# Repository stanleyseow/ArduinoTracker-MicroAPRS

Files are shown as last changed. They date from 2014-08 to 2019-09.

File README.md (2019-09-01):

Arduino APRS SVTrackR
=====================

 - Written by Stanley Seow ( 9W2SVT / N5SVT )
 - e-mail : stanleyseow@gmail.com
 
 *** Pls refer to the top of the source code for version history and updated instructions.

 This sketch configure the MicroAPRS (the modem) for the proper callsign and ssid and read/write data coming in from the MicroAPRS (another Arduino/atmega328P with bootloader) via Serial port

 Library needed :-
 
 * AltSoftSerial ( https://www.pjrc.com/teensy/td_libs_AltSoftSerial.html )
 * tinyGPS++ ( http://arduiniana.org/libraries/tinygpsplus/ )
 * SSD1306 OLED Text only ( https://github.com/stanleyseow/ArduinoTracker-MicroAPRS/tree/master/libraries/SSD1306_text )
 * MicroAPRS libs 
 
 Instructions :-
 
 Download the MicroAPRS compiled Modem.hex from https://github.com/markqvist/MicroAPRS/
 
 As this hex is not compiled from the Arduino IDE, you need to manually upload this hex to the Arduino with a bootloader using avrdude or Xloader.
 
Xloader to load this hex image to the Arduino / Mini Pro :-
 
    1. Download the Xloader : http://russemotto.com/xloader/
    2. Copy modem.hex into Xloader folder
    3. Select the modem hex file 
    4. Select UNO for UNO or Duemilanove/328 for Mini Pro
    5. Select the COM port and press Upload

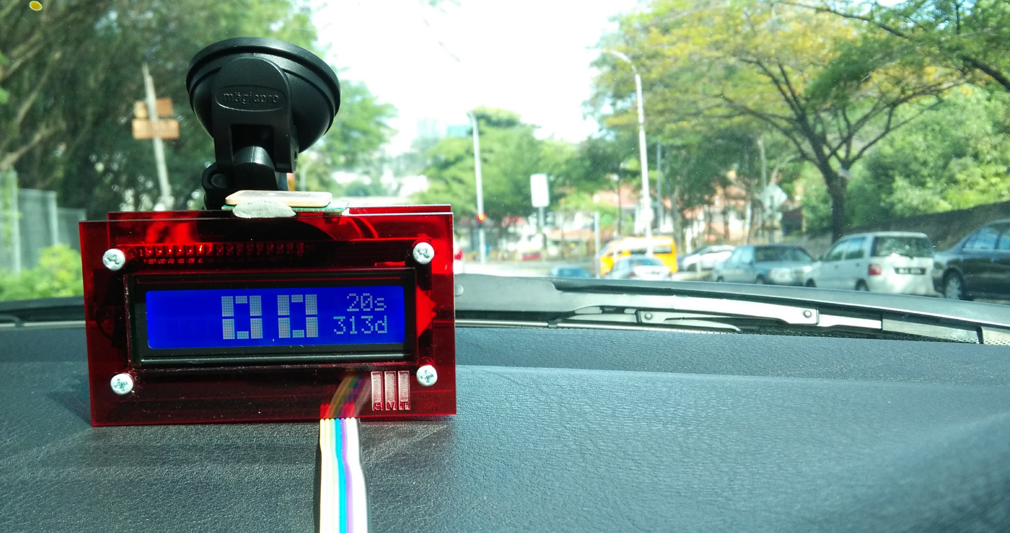
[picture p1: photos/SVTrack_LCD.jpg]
SVTrack LCD
 

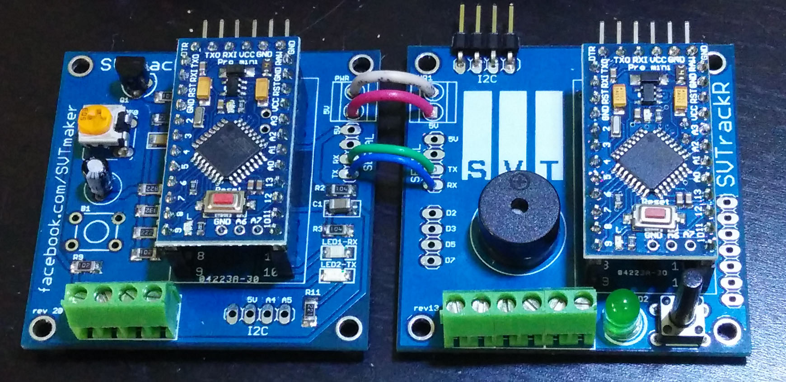
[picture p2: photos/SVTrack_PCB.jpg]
SVTrack PCB
    
    
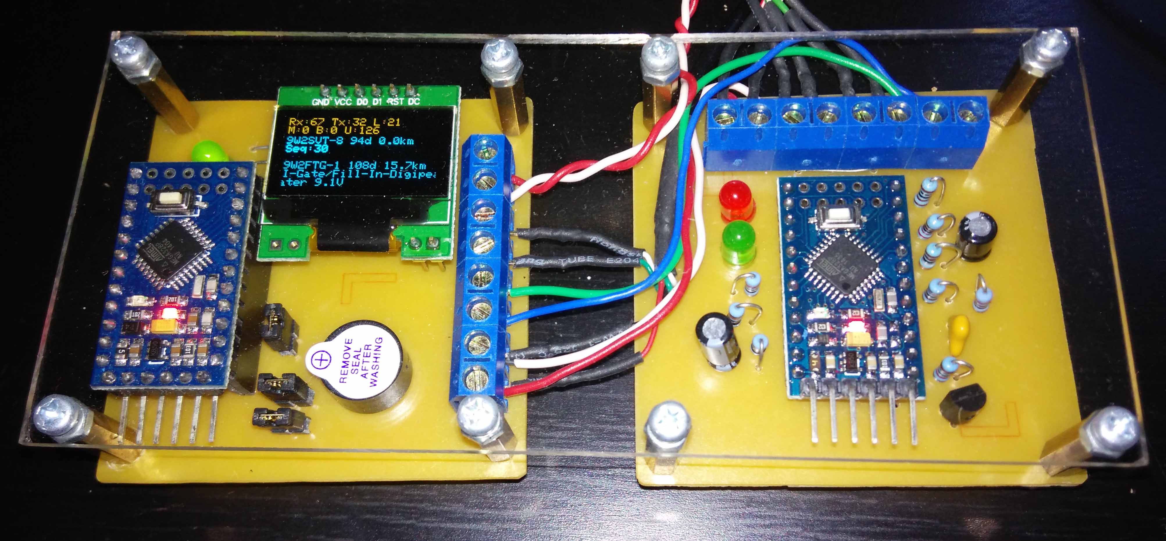
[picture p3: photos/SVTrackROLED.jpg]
SVTrackR with OLED


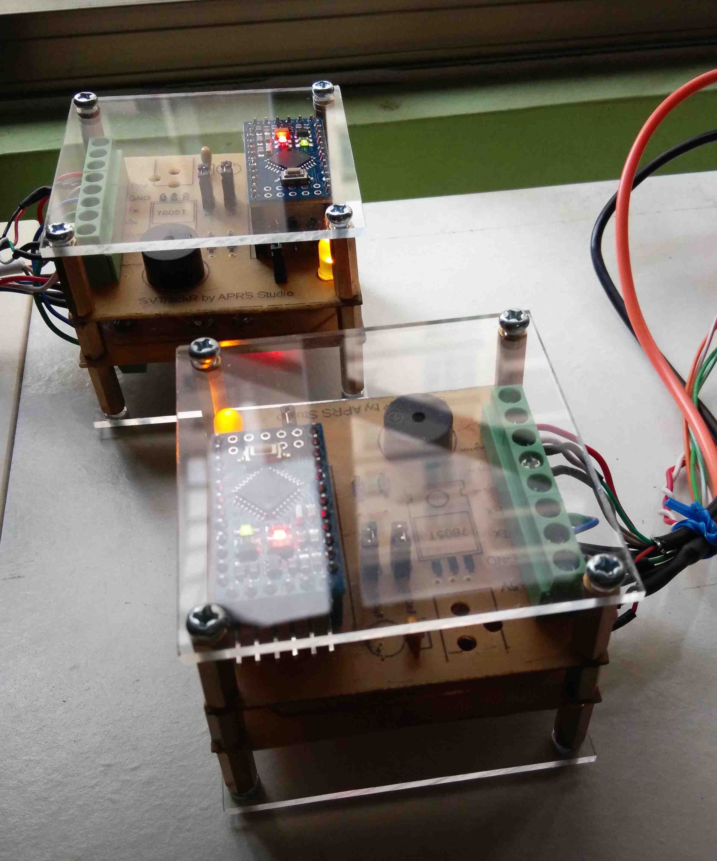
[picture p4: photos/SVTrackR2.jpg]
SVTrackR


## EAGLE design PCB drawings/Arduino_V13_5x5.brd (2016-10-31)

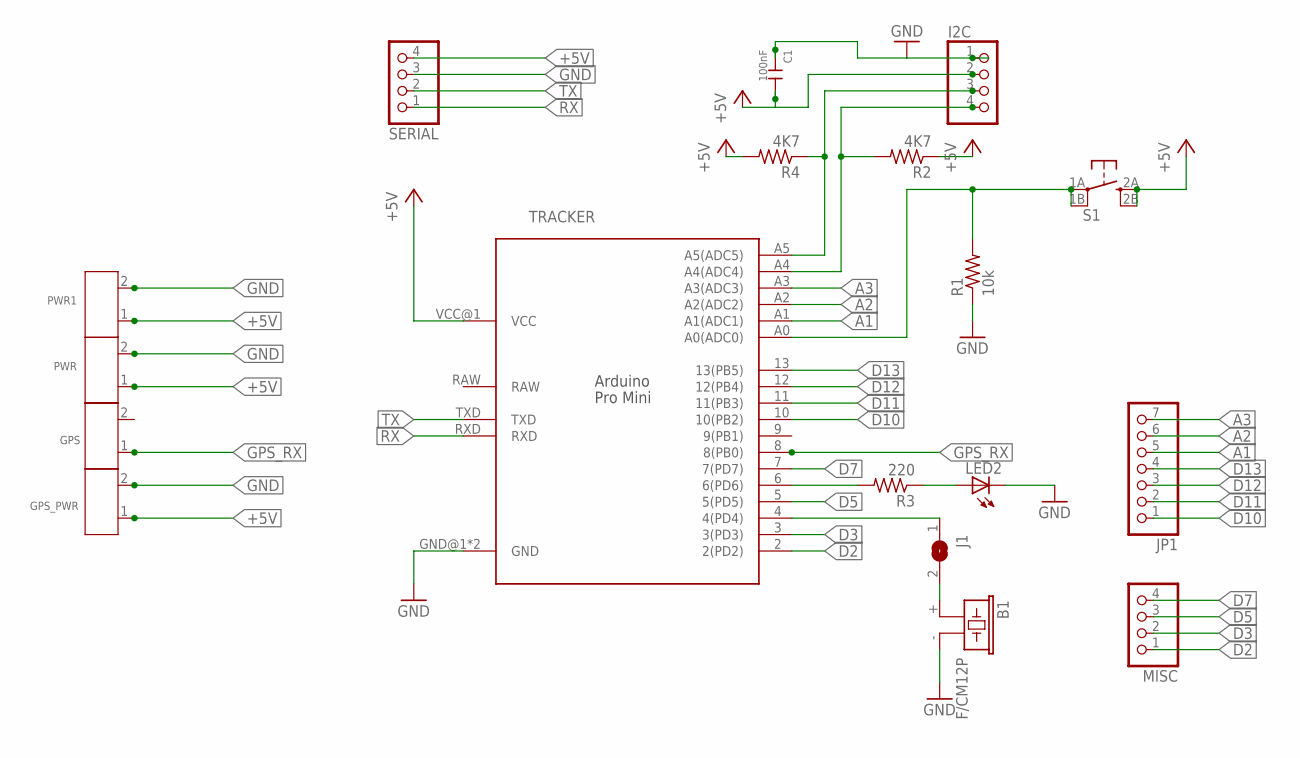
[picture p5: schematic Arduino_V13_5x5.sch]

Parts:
B1: F/CM12P
C1: 100nF; C1206
GPS: SCREW-TERMINAL-GREEN(2P-3.5); H2-3.5-7.0X7.0MM
GPS_PWR: SCREW-TERMINAL-GREEN(2P-3.5); H2-3.5-7.0X7.0MM
I2C: PINHD-1X4; 1X04
J1: SJ
JP1: PINHD-1X7; 1X07
LED2: LED5MM
MISC: PINHD-1X4; 1X04
PWR, PWR1: SCREW-TERMINAL-GREEN(2P-3.5); H2-3.5-7.0X7.0MM
R1: 10k; M1206
R2, R4: 4K7; M1206
R3: 220; M1206
S1: TACTILETACT-6X6-PTH; TACTILE-PTH
SERIAL: PINHD-1X4; 1X04
TRACKER: PRO-MINI

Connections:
+5V: C1.2, GPS_PWR.1, I2C.2, PWR.1, PWR1.1, R2.1, R4.2, S1.2A, S1.2B, SERIAL.4, TRACKER.VCC@1 (VCC)
A1: JP1.5, TRACKER.A1 (A1(ADC1))
A2: JP1.6, TRACKER.A2 (A2(ADC2))
A3: JP1.7, TRACKER.A3 (A3(ADC3))
A4: I2C.4, R2.2, TRACKER.A4 (A4(ADC4))
BUTTON: R1.2, S1.1A, S1.1B, TRACKER.A0 (A0(ADC0))
BUZZER: J1.1, TRACKER.4 (4(PD4))
D2: MISC.1, TRACKER.2 (2(PD2))
D3: MISC.2, TRACKER.3 (3(PD3))
D5: MISC.3, TRACKER.5 (5(PD5))
D7: MISC.4, TRACKER.7 (7(PD7))
D10: JP1.1, TRACKER.10 (10(PB2))
D11: JP1.2, TRACKER.11 (11(PB3))
D12: JP1.3, TRACKER.12 (12(PB4))
D13: JP1.4, TRACKER.13 (13(PB5))
GND: B1.- (2), C1.1, GPS_PWR.2, I2C.1, LED2.K (C), PWR.2, PWR1.2, R1.1, SERIAL.3, TRACKER.GND@1 (GND), TRACKER.GND@2 (GND)
GPS_RX: GPS.1, TRACKER.8 (8(PB0))
unnamed: I2C.3, R4.1, TRACKER.A5 (A5(ADC5))
unnamed: LED2.A, R3.1
unnamed: R3.2, TRACKER.6 (6(PD6))
unnamed: B1.+ (1), J1.2
RX: SERIAL.1, TRACKER.RXD
TX: SERIAL.2, TRACKER.TXD

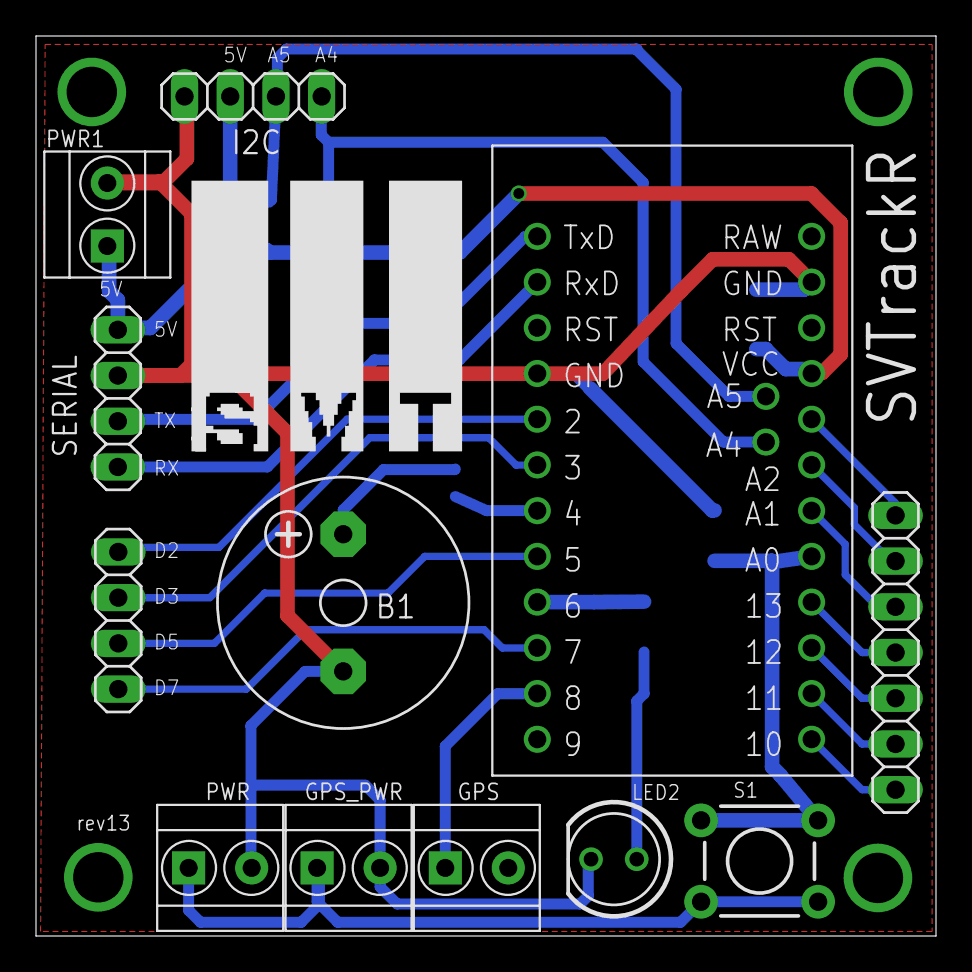
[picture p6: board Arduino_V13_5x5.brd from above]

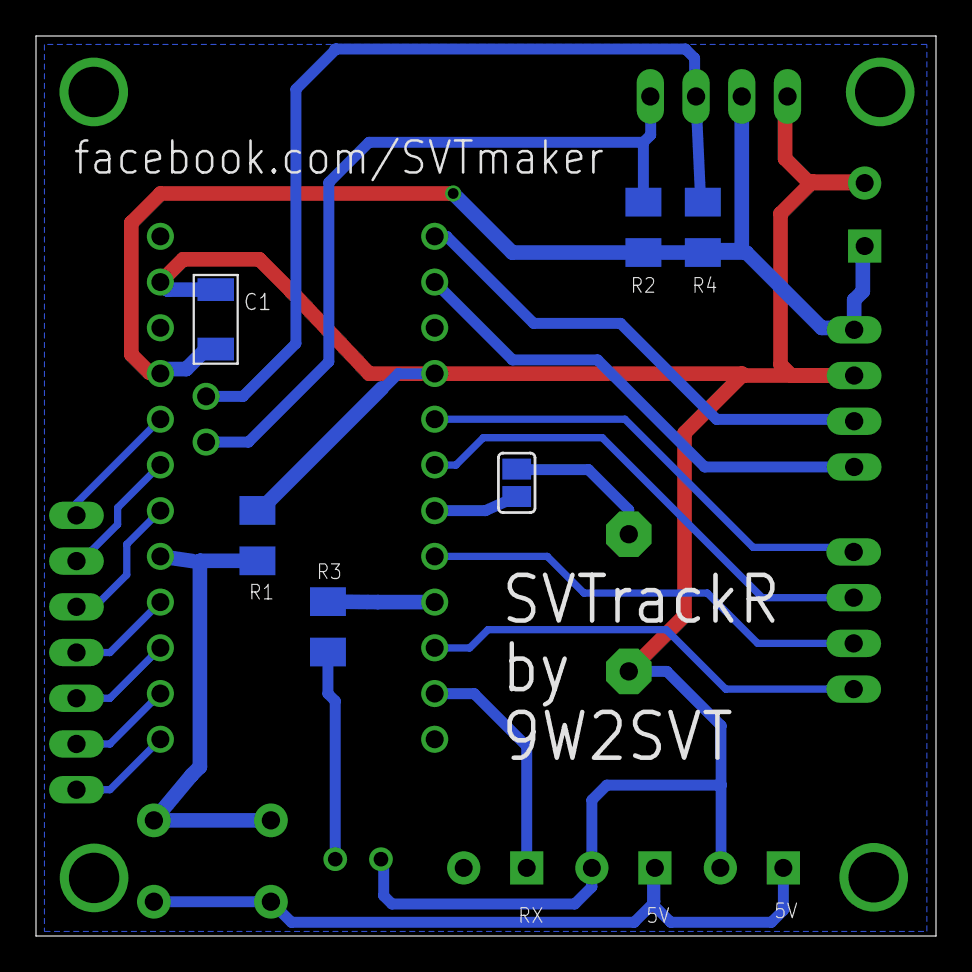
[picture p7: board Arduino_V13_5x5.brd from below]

Board: 2 copper layers, 50.0 x 50.0 mm, 18 parts (6 on the bottom side), 23 nets.

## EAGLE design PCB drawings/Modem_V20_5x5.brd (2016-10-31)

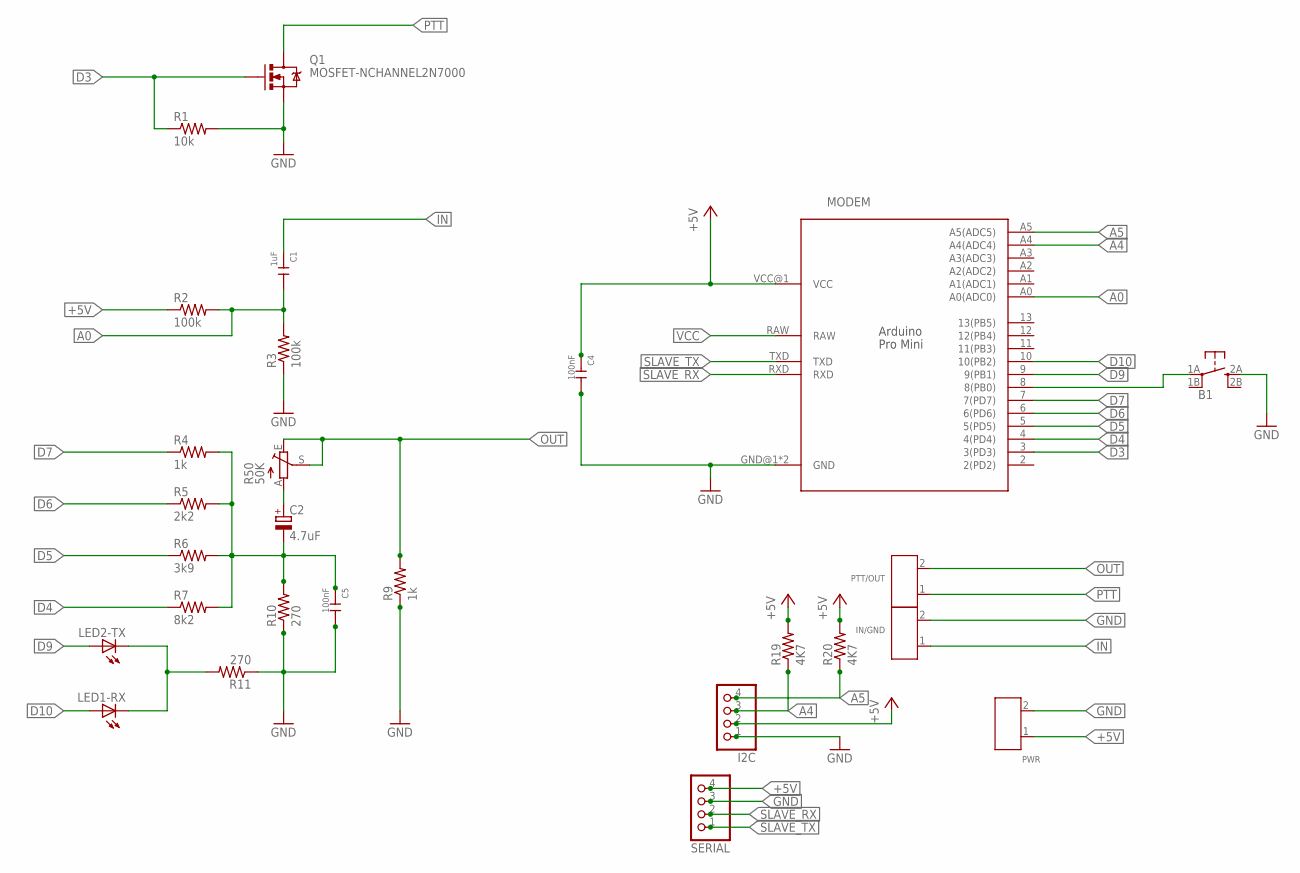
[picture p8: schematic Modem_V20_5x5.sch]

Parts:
B1: TACTILETACT-6X6-PTH; TACTILE-PTH
C1: 1uF; C1206
C2: 4.7uF; E2,5-6
C4, C5: 100nF; C1206
I2C: PINHD-1X4; 1X04
IN/GND: SCREW-TERMINAL-GREEN(2P-3.5); H2-3.5-7.0X7.0MM
LED1-RX, LED2-TX: LED1206; LED-1206
MODEM: PRO-MINI
PTT/OUT: SCREW-TERMINAL-GREEN(2P-3.5); H2-3.5-7.0X7.0MM
PWR: SCREW-TERMINAL-GREEN(2P-3.5); H2-3.5-7.0X7.0MM
Q1: MOSFET-NCHANNEL2N7000; TO-92
R1: 10k; R1206
R2, R3: 100k; R1206
R4, R9: 1k; R1206
R5: 2k2; R1206
R6: 3k9; R1206
R7: 8k2; R1206
R10, R11: 270; R1206
R19, R20: 4K7; R1206
R50: 50K; CA6V
SERIAL: PINHD-1X4; 1X04

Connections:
+5V: C4.1, I2C.2, MODEM.VCC@1 (VCC), PWR.1, R2.1, R19.2, R20.2, SERIAL.4
A0: C1.2, MODEM.A0 (A0(ADC0)), R2.2, R3.2
A4: I2C.3, MODEM.A4 (A4(ADC4)), R19.1
A5: I2C.4, MODEM.A5 (A5(ADC5)), R20.1
D3: MODEM.3 (3(PD3)), Q1.2 (G), R1.1
D4: MODEM.4 (4(PD4)), R7.1
D5: MODEM.5 (5(PD5)), R6.1
D6: MODEM.6 (6(PD6)), R5.1
D7: MODEM.7 (7(PD7)), R4.1
D8: B1.1A, MODEM.8 (8(PB0))
D9: LED2-TX.A, MODEM.9 (9(PB1))
D10: LED1-RX.A, MODEM.10 (10(PB2))
GND: B1.2A, C4.2, C5.2, I2C.1, IN/GND.2, MODEM.GND@1 (GND), MODEM.GND@2 (GND), PWR.2, Q1.1 (S), R1.2, R3.1, R9.1, R10.1, R11.1, SERIAL.3
IN: C1.1, IN/GND.1
unnamed: C2.+, R50.A
unnamed: LED1-RX.C, LED2-TX.C, R11.2
unnamed: C2.-, C5.1, R4.2, R5.2, R6.2, R7.2, R10.2
OUT: PTT/OUT.2, R9.2, R50.E, R50.S
PTT: PTT/OUT.1, Q1.3 (D)
SLAVE_RX: MODEM.RXD, SERIAL.2
SLAVE_TX: MODEM.TXD, SERIAL.1
VCC: MODEM.RAW

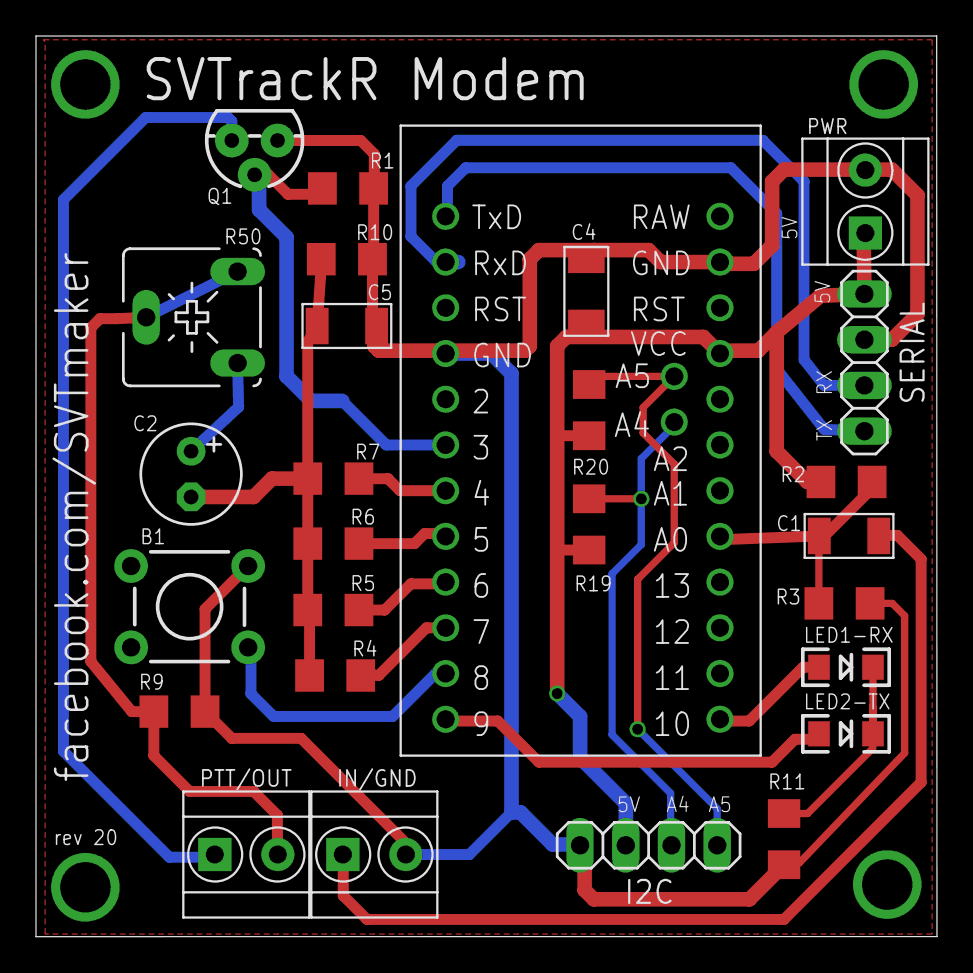
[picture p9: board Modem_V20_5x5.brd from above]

Board: 2 copper layers, 50.1 x 50.0 mm, 27 parts (0 on the bottom side), 21 nets.

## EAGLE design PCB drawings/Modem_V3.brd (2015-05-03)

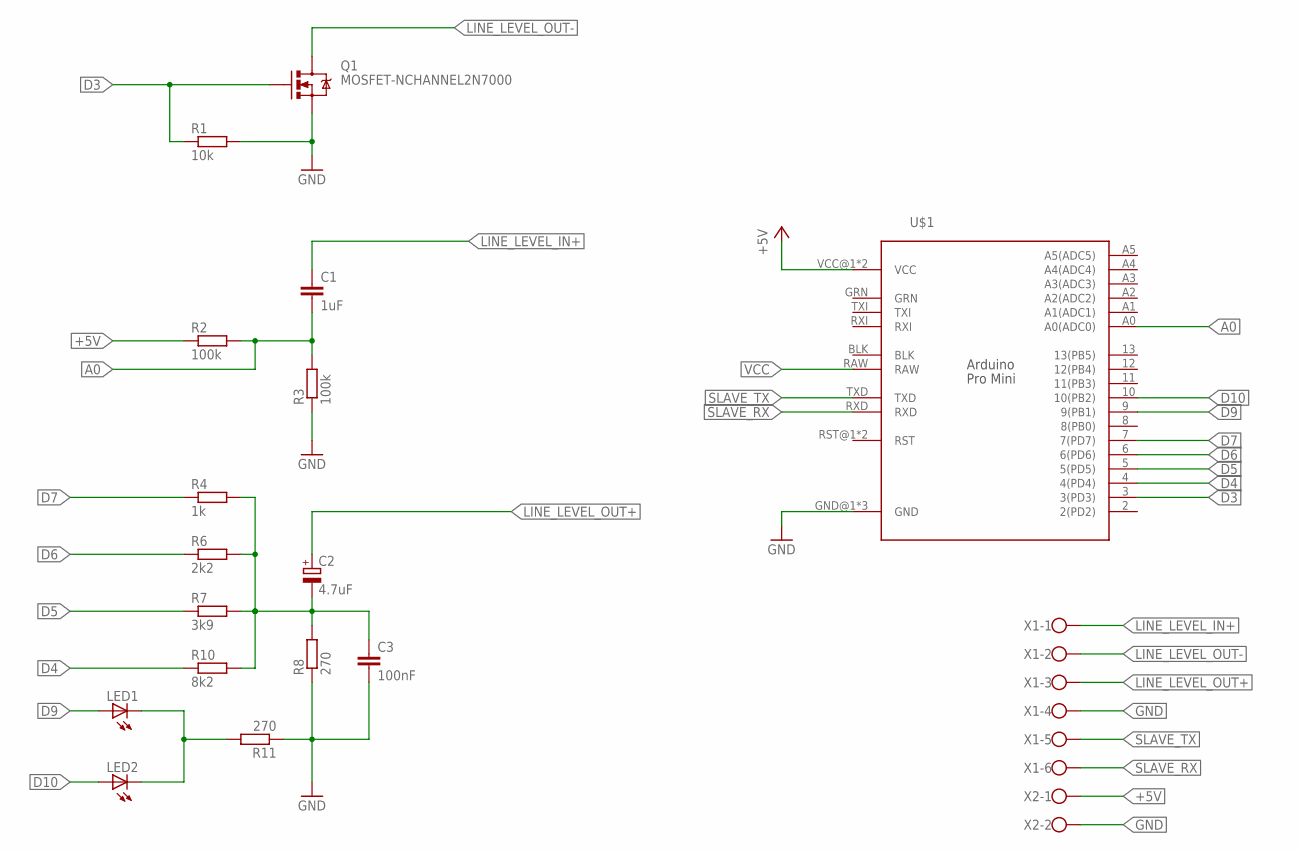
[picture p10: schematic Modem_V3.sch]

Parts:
C1: 1uF; C025-030X050
C2: 4.7uF; E2,5-6
C3: 100nF; C025-030X050
LED1, LED2: LED5MM
Q1: MOSFET-NCHANNEL2N7000; TO-92
R1: 10k; 0207/2V
R2, R3: 100k; 0207/2V
R4: 1k; 0207/2V
R6: 2k2; 0207/2V
R7: 3k9; 0207/2V
R8, R11: 270; 0207/2V
R10: 8k2; 0207/2V
U$1: PRO-MINI
X1: W237-6
X2: W237-102

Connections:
+5V: R2.1, U$1.VCC@1 (VCC), U$1.VCC@2 (VCC), X2.1
A0: C1.2, R2.2, R3.2, U$1.A0 (A0(ADC0))
D3: Q1.2 (G), R1.1, U$1.3 (3(PD3))
D4: R10.1, U$1.4 (4(PD4))
D5: R7.1, U$1.5 (5(PD5))
D6: R6.1, U$1.6 (6(PD6))
D7: R4.1, U$1.7 (7(PD7))
D9: LED1.A, U$1.9 (9(PB1))
D10: LED2.A, U$1.10 (10(PB2))
GND: C3.2, Q1.1 (S), R1.2, R3.1, R8.1, R11.1, U$1.GND@1 (GND), U$1.GND@2 (GND), U$1.GND@3 (GND), X1.4, X2.2
LINE_LEVEL_IN+: C1.1, X1.1
LINE_LEVEL_OUT+: C2.+, X1.3
LINE_LEVEL_OUT-: Q1.3 (D), X1.2
unnamed: LED1.K (C), LED2.K (C), R11.2
unnamed: C2.-, C3.1, R4.2, R6.2, R7.2, R8.2, R10.2
SLAVE_RX: U$1.RXD, X1.6
SLAVE_TX: U$1.TXD, X1.5
VCC: U$1.RAW

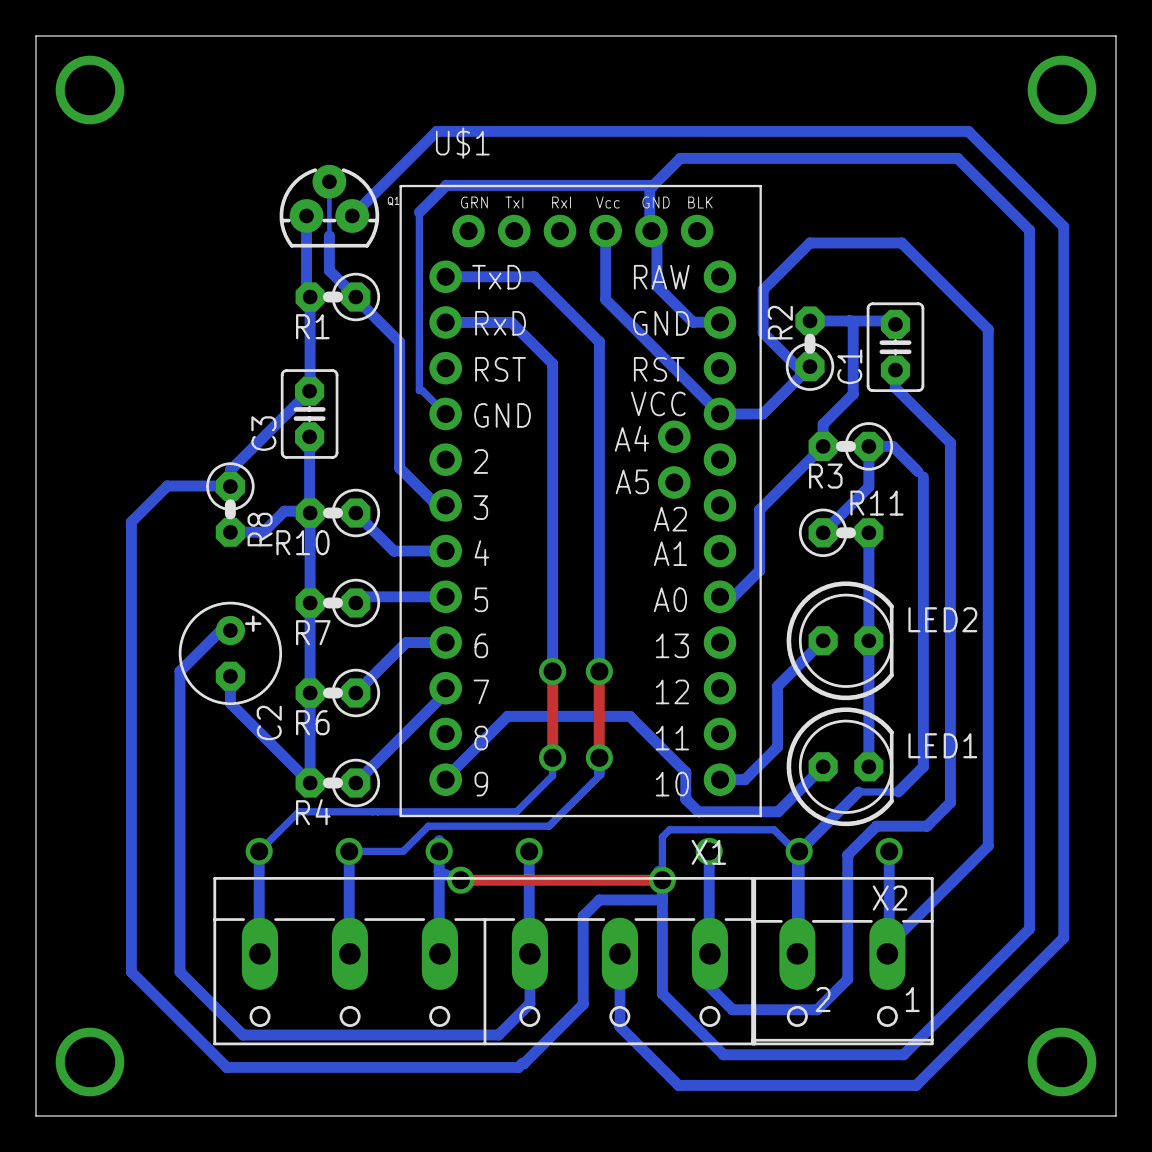
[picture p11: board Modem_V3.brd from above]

Board: 2 copper layers, 60.0 x 60.0 mm, 18 parts (0 on the bottom side), 17 nets.

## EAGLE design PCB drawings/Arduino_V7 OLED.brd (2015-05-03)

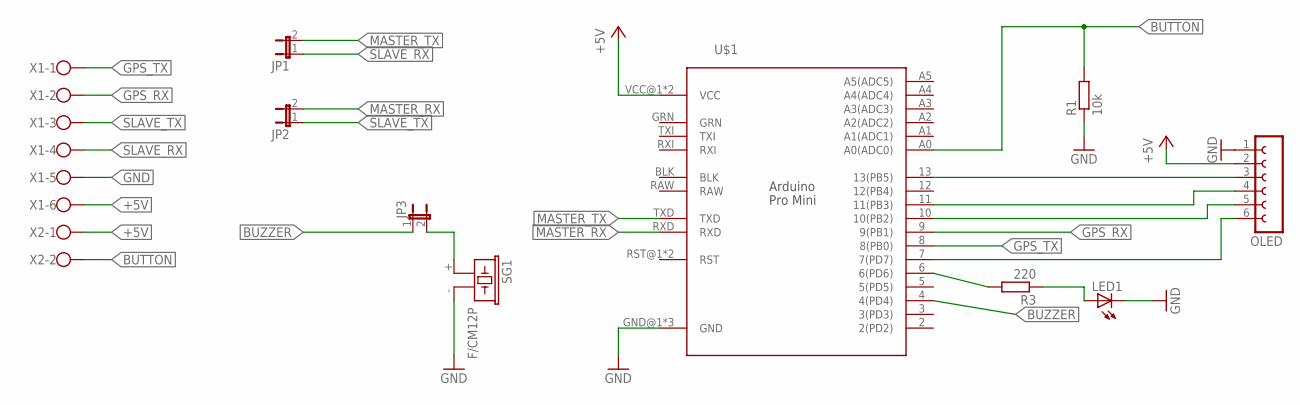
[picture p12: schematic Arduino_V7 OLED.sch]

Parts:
JP1, JP2, JP3: JP1E; JP1
LED1: LED5MM
OLED: FE06-1; FE06
R1: 10k; 0207/10
R3: 220; 0207/10
SG1: F/CM12P
U$1: PRO-MINI
X1: W237-6
X2: W237-102

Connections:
+5V: OLED.2, U$1.VCC@1 (VCC), U$1.VCC@2 (VCC), X1.6, X2.1
BUTTON: R1.2, U$1.A0 (A0(ADC0)), X2.2
BUZZER: JP3.1, U$1.4 (4(PD4))
CS: OLED.6, U$1.7 (7(PD7))
DI: OLED.4, U$1.11 (11(PB3))
GND: LED1.K (C), OLED.1, R1.1, SG1.- (2), U$1.GND@1 (GND), U$1.GND@2 (GND), U$1.GND@3 (GND), X1.5
GPS_RX: U$1.9 (9(PB1)), X1.2
GPS_TX: U$1.8 (8(PB0)), X1.1
MASTER_RX: JP2.2, U$1.RXD
MASTER_TX: JP1.2, U$1.TXD
unnamed: OLED.3, U$1.13 (13(PB5))
unnamed: LED1.A, R3.1
unnamed: R3.2, U$1.6 (6(PD6))
unnamed: JP3.2, SG1.+ (1)
RST: OLED.5, U$1.10 (10(PB2))
SLAVE_RX: JP1.1, X1.4
SLAVE_TX: JP2.1, X1.3

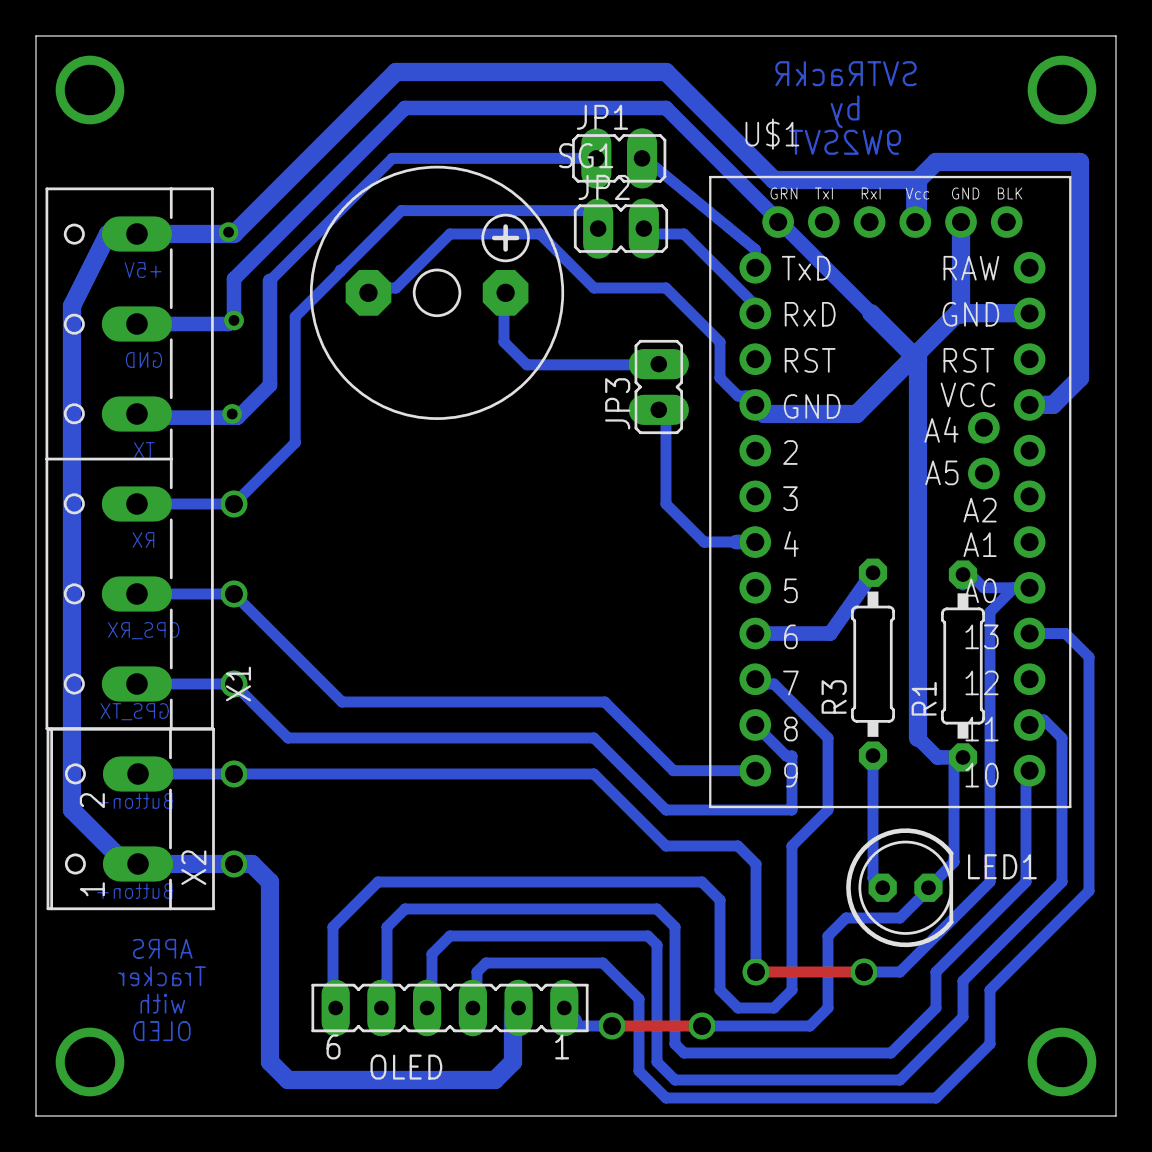
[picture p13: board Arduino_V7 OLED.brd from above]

Board: 2 copper layers, 60.0 x 60.0 mm, 11 parts (0 on the bottom side), 17 nets.

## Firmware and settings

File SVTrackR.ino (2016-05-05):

// Current Version
#define VERSION "SVTrackR v1.63 " 

/*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
 github URL :-
 https://github.com/stanleyseow/ArduinoTracker-MicroAPRS
 
 This sketch configure the MicroAPRS for the proper callsign and ssid and
 read/write data coming in from the MicroAPRS via debug port
 
 Pin 0/1 (rx,tx) connects to Arduino with MicroAPRS firmware
 Pin 8,9 ( rx,tx ) connects to GPS module
 Pin 2,3 connect to debug serial port
 
 Pin 4 - Buzzer during Radio Tx
 
 Date : 03 July 2014
 Written by Stanley Seow
 e-mail : stanleyseow@gmail.com
  
 History :-
 03 July 2014 :-
 - Initial released
 
 06 July 2014 :-
 - added checks for speed and idle speed, modify the Txinternal
 - remove all debug Monitor output
 
 12 July 2014 :-
 - Added SmartBeaconing algorithm, Tx when turn is more than 25 deg
 - Reduce the Tx interval
 
 14 July 2014 :-
 - Fixed coordinates conversion from decimal to Deg Min formula
 - Formula to calculate distance from last Tx point so that it will Tx once the max direct distance 
  of 500m is reached
 
 18 July 2014 :-
 - Fixed lastTx checking routine and ensure lastTx is 5 or more secs
 - Check for analog0 button at least 10 secs per Tx
 - Rewrote the DecodeAPRS functions for display to LCD only
 
 1 Aug 2014 :-
 - Ported codes to Arduino Mini Pro 3.3V
 - Due to checksum errors and Mini Pro 3.3V 8Mhz on SoftwareSerial, I swapped GPS ports to AltSoftwareSerial
 
 3 Aug 2014 :-
 - Added #define codes to turn on/off LCD, DEBUG and TFT
 - Added TFT codes for 2.2" SPI TFT ( runs on 3.3V )
 - Added the F() macros to reduce memory usages on static texts
 
 6 Aug 2014
 - Added Course/Speed/Alt into comment field readable by aprs.fi
 
 10 Aug 2014
 - Added support for teensy 3.1 (mcu ARM Cortex M4) 
 
 19 Aug 2014
 - Added GPS simulator codes
 - Added Tx status every 10 Tx
 - Added counter for Headins, Time, Distance and Button
 
 19 Sep 2014
 - Modify button pressed to send STATUS & position 
 - If GPS not locked, only sent out STATUS 
 
 24 Sep 2014
 - Added support for BD GPS by modifying the tinyGPSPlus 
 
 15 Oct 2014
 - Added setting PATH1 & PATH2 to the modem 
 
 24 Oct 2014 
 - Added blinking LED 13 during configuring the modem and a beep when completed
 - Minor changes in Status codes
 
 18 Nov 2014 ( v0.9 )
 - Adding OLED text only display to the Tracker
 - Moving LED to pin 6 as OLED used up SPI pins of 13,11,10,7
 - Switch top 2 lines from gps info to tracker info ( packet rx,tx)
 
 1 Dec 2014 ( v1.0 )
 - Added mic-e/compressed packets decoding from MicroAPRS libs
 - Ability to display received messages
 24 Dec 2014 ( v1.1 )
 - Added comment parsing codes from latest MicroAPRS libs
 - Added status ">" type parsing
 
 20 Jan 2015 ( v1.2 )
 - Modify Tx position before Tx status with 3 secs delay
 
 25 Jan 2015 ( V1.3 )
 - Added smartDelay for Tx status to display any received packets during the smartDelay period
 - Added 2 short beeps if Rx station is within 500m away
 
  15 Mar 2015 ( v1.4 - lamaral )
 - Fixed the hardcoding of the North and East on the GPS position
 - Added custom comment on APRS packet 
 - Appended "0" if Lat/Lng is less than 10 deg
  
  23 Mar 2015 ( v1.5 - lamaral )
 - Fixed the problem of appending a zero to negative coordinates
 - Created the beep(int) function to save some memory
  
  07 Apr 2015 ( v1.5a - stanleyseow )
  - fixed the Lontitide with hard coded 0, will give coordinates errors if Lontitide is above 100 deg
  - fixed OLED display for above errors
  
  24 Apr 2015 ( v1.6 - stanleyseow )
  - append recevied callsign and distance to the end of comment
  - fixes some txTimer and lastTx codes
  - changed TxtoRadio return value to boolean and reason for Tx trigger
  - removed unused variables  
  
  4 May 2015 ( v1.61 stanleyseow )
  - Change OLED callsign textsize 2
  - single page packet decode
  - minor changes to comment strings

  31 Aug 2015 ( V1.62 stanleyseow )
  - Adding support for I2C 16x2 for Dashboard LCD
  - Added 3 screens for speed/sats/headings, date/pos and other stats
  - Added N/E/S/W into main screen

    11 Apr 2016 ( V1.63 stanleyseow )
  - Changed to 500km away station calculations
  - Line 657
  - rev13 PCB will change to pullup circuit and read using digitalRead() instead of analogRead


*/

// Needed this to prevent compile error for #defines
#if 1
__asm volatile ("nop");
#endif

#ifndef _CONFIGURATION_INCLUDED
#define _CONFIGURATION_INCLUDED
#include "config.h"
#endif
 
// GPS libraries
// Choose between GPS and BD
//#include <TinyGPS++BD.h>
#include <TinyGPS++.h>
TinyGPSPlus gps;
// The packet decoding libs
#include <MicroAPRS.h>

MicroAPRS microaprs = MicroAPRS(&Serial);
// APRS Buffers
#define BUFLEN (260) //original 260
char packet[BUFLEN];
int buflen = 0;
bool showmsg, showstation;



float latitude = 0.0;
float longitude = 0.0;
float wayPointLatitude, wayPointLongitude;
float latitudeRadians, wayPointLatitudeRadians, longitudeRadians, wayPointLongitudeRadians;
float distanceToWaypoint, bearing, deltaLatitudeRadians, deltaLongitudeRadians;
const float pi = 3.14159265;
const int radiusOfEarth = 6371; // in km

// Turn on/off debug, on by default on pin 2,3
#undef DEBUG

// Turn on/off 16x2 I2C LCD
#define I2C16X2


// ifdef for I2C LCD
#ifdef I2C16X2
	#include <Wire.h>
	#include <LiquidCrystal_I2C.h>
//	LiquidCrystal_I2C lcd(0x27,16,2); // 0x20 is adresss for LCC 16x2
  LiquidCrystal_I2C lcd(0x3F,16,2); // 0x20 is adresss for LCC 16x2

#endif


// Turn on/off 0.96" OLED

#undef OLED

#ifdef DEBUG 
  #if defined(__arm__) && defined(TEENSYDUINO)
  #else
  #include <SoftwareSerial.h>
  #endif
#endif


// AltSoftSerial default on UNO is 8,9 (Rx,Tx)
#if defined (__AVR_ATmega328P__) 
#include <AltSoftSerial.h>
  AltSoftSerial ss(8,9);
#else
// Map hw Serial2 to ss for gps port for other platform with hw serial
  #define ss Serial2 
#endif


#ifdef DEBUG
// Connect to GPS module on pin 9, 10 ( Rx, Tx )
  #if defined (__AVR_ATmega328P__) 
    SoftwareSerial debug(2,3);
  #elif defined(__arm__) && defined(TEENSYDUINO)
    #define debug Serial3
  #endif
#endif

//////////////////////////////////////////////////////////////////////////////////////////////////////////////
// Put All global defines here
//////////////////////////////////////////////////////////////////////////////////////////////////////////////

const byte buzzerPin = 4;
const byte ledPin = 6;


// Defines for OLED 128x64 
#ifdef OLED
#include <SPI.h>
#include <SSD1306_text.h>
#include <stdlib.h>
// Hardware SPI pins include D11=Data and D13=Clk
// DO = CLK, 13
// DI = MOSI, 11
#define OLED_DC 7 // OLED Label DC
#define OLED_CS 0 // OLED Not used
#define OLED_RST 10 // OLED Label RST
SSD1306_text oled(OLED_DC, OLED_RST, OLED_CS);
#endif

// Varables for Packet Decode
const unsigned int MAX_INPUT = 103;
static unsigned int packetDecoded = 0;

char *lastCall="";
String rxCallsign="";
unsigned int rxStation;

unsigned int mCounter = 0;
unsigned int txCounter = 0;
unsigned long txTimer = 0;
#ifdef I2C16X2
bool packetDisplay = 0;
unsigned long displayTime = 0;
#endif
unsigned long lastTx = 0;
unsigned long lastRx = 0;
unsigned long txInterval = 80000L;  // Initial 80 secs internal

int lastCourse = 0;
byte lastSpeed = 0;
byte buttonPressed = 0;

// Unused
//static unsigned int Hd,Ti,Di,Bn = 0;

int previousHeading, currentHeading = 0;
// Initial lat/lng pos, change to your base station coordnates
float lastTxLat = HOME_LAT;
float lastTxLng = HOME_LON;
float lastTxdistance, homeDistance, base = 0.0;

// Used in the future for sending messages, commands to the tracker
const unsigned int MAX_DEBUG_INPUT = 30;


#ifdef I2C16X2
/// LCD Large fonts
// the 8 arrays that form each segment of the custom numbers

/*
byte LT[8] = 
{
  B00011,
  B00111,
  B01111,
  B01111,
  B01111,
  B01111,
  B01111,
  B01111
};*/

byte UB[8] =
{
  B11111,
  B11111,
  B11111,
  B00000,
  B00000,
  B00000,
  B00000,
  B00000
};

byte RT[8] =
{
  B11100,
  B11110,
  B11111,
  B11111,
  B11111,
  B11111,
  B11111,
  B11111
};

byte LL[8] =
{
  B01111,
  B01111,
  B01111,
  B01111,
  B01111,
  B01111,
  B00111,
  B00011
};

byte LB[8] =
{
  B00000,
  B00000,
  B00000,
  B00000,
  B00000,
  B11111,
  B11111,
  B11111
};
/*
byte LR[8] =
{
  B11111,
  B11111,
  B11111,
  B11111,
  B11111,
  B11111,
  B11110,
  B11100
};
*/
byte UMB[8] =
{
  B11111,
  B11111,
  B11111,
  B00000,
  B00000,
  B00000,
  B11111,
  B11111
};
byte LMB[8] =
{
  B11111,
  B00000,
  B00000,
  B00000,
  B00000,
  B11111,
  B11111,
  B11111
};

int x = 0;

/// LCD Large fonts
#endif

//////////////////////////////////////////////////////////////////////////////
// setup()
//////////////////////////////////////////////////////////////////////////////

void setup()
{
  
#ifdef I2C16X2
  lcd.init();

  lcd.createChar(1,RT);  
  lcd.createChar(2,UB);
//  lcd.createChar(3,LL);
  lcd.createChar(4,LB);
//  lcd.createChar(5,LR);  
  lcd.createChar(6,UMB);
  lcd.createChar(0,LMB);
//  lcd.createChar(8,LT);
  
  lcd.backlight();
  lcd.begin(16,2);
  
  lcd.print(VERSION);
  delay(1000);
#endif


#ifdef OLED
    oled.init();
    oled.clear();                 // clear screen

    oled.setTextSize(1,1);        // 5x7 characters, pixel spacing = 1
    oled.setCursor(0,0);          // move cursor to row 1, pixel column 100
    oled.write(VERSION);
    
    oled.setTextSize(1,1);        // 5x7 characters, pixel spacing = 1
    oled.setCursor(1,0);          // move cursor to row 1, pixel column 100
    oled.write("by APRS Studio");  
    delay(2000);
#endif

#if defined(__arm__) && defined(TEENSYDUINO)
// This is for reading the internal reference voltage
  analogReference(EXTERNAL);
  analogReadResolution(12);
  analogReadAveraging(32);
#endif

// Buzzer uses pin 4
  pinMode(buzzerPin, OUTPUT);

  // LED pin on 13, only enable for non-SPI TFT
  pinMode(ledPin,OUTPUT);

// Main serial talks to the MicroModem directly
Serial.begin(9600);

// ss talks to the GPS receiver at 9600 
ss.begin(9600);


#ifdef DEBUG
  debug.begin(9600);
#endif


#ifdef DEBUG
  debug.flush();
  debug.println();
  debug.print(F("DEBUG:- ")); 
  debug.println(F(VERSION)); 
  debug.println();
#endif

  // Set a delay for the MicroAPRS to boot up before configuring it
  delay(1000);
  configModem();
  
  Serial.flush();
  
  txTimer = millis();
  
#ifdef OLED  
  oled.clear();
  oledLine1();
#endif  

} // end setup()

//////////////////////////////////////////////////////////////////////////////
// loop()
//////////////////////////////////////////////////////////////////////////////

void loop()
{
    // Speed in km/h
    const byte highSpeed = 80;       // High speed  
    const byte lowSpeed = 30;        // Low speed
    char c;
    boolean inputComplete = false;
    int headingDelta = 0;
    
#ifdef DEBUG    
    // Send commands from debug serial into hw Serial char by char 

#if defined (__AVR_ATmega328P__)    
    debug.listen();
#endif  
#endif  

// Turn on listen() on GPS
#if defined (__AVR_ATmega328P__)        
    ss.listen();  
#endif    
    while ( ss.available() > 0 ) {
      gps.encode(ss.read());
    }
    
    
  while (Serial.available() > 0)
  {
	char ch = microaprs.read();
	if (ch == '\n')
	{
		packet[buflen] = 0;
		show_packet();
		buflen = 0;
	}
	else if ((ch > 31 || ch == 0x1c || ch == 0x1d || ch == 0x27) && buflen < BUFLEN)
	{
		// Mic-E uses some non-printing characters
		packet[buflen++] = ch;
	}
  }

///////////////// Triggered by location updates /////////////////////// 
   if ( gps.location.isUpdated() ) { 

     homeDistance = TinyGPSPlus::distanceBetween(
          gps.location.lat(),
          gps.location.lng(),
          HOME_LAT, 
          HOME_LON);   
          
    lastTxdistance = TinyGPSPlus::distanceBetween(
          gps.location.lat(),
          gps.location.lng(),
          lastTxLat,
          lastTxLng);
          
    base = TinyGPSPlus::distanceBetween(
          gps.location.lat(),
          gps.location.lng(),
          HOME_LAT, 
          HOME_LON)/1000; 
          
     latitude = gps.location.lat();
     longitude = gps.location.lng();   
          
      // Get headings and heading delta
      currentHeading = (int) gps.course.deg();
      if ( currentHeading >= 180 ) { 
      currentHeading = currentHeading-180; 
      }
      headingDelta = (int) ( previousHeading - currentHeading ) % 360;   
     
    } // endof gps.location.isUpdated()

///////////////// Triggered by time updates /////////////////////// 
// Update LCD every second

   if ( gps.time.isUpdated() ) {   
    
   if ( gps.satellites.value() > 3 ) {
     digitalWrite(ledPin,HIGH);  
   } else {
     digitalWrite(ledPin,LOW);     
   }





    if ( gps.time.second() % 10 == 0 ) { 
#ifdef OLED
      oled.setTextSize(1,1);        // 5x7 characters, pixel spacing = 1
      oledLine2();
#endif      
  } else if ( gps.time.second() % 5 == 0 ) {
#ifdef OLED    
      oled.setTextSize(1,1);        // 5x7 characters, pixel spacing = 1
      oledLine1();
#endif
  } 
  
// I2C LCD addons
#ifdef I2C16X2
  if ( packetDisplay ) {
     // Do not overwrite the decoded packet
     // display packetDecoded for 10 secs
     if ( millis() - displayTime > 10000 ) {
           packetDisplay = 0;
     }
  } else if ( gps.time.second() > 30 && gps.time.second() < 36 ) {
      lcdScreen3(); // Screen1 is speed / sats
  } else if ( gps.time.second() > 50 && gps.time.second() < 56 ) { 
      lcdScreen2(); // Screen2 is Altitide / bearing / distBase / Uptime / Rx / Tx / Msgs
   } else {
      lcdScreen1(); // Screen1 is speed / sats 
   }
#endif     


// Change the Tx internal based on the current speed
// This change will not affect the countdown timer
// Based on HamHUB Smart Beaconing(tm) algorithm

      if ( gps.speed.kmph() < 5 ) {
            txInterval = 300000;         // Change Tx internal to 5 mins
       } else if ( gps.speed.kmph() < lowSpeed ) {
            txInterval = 70000;          // Change Tx interval to 60
       } else if ( gps.speed.kmph() > highSpeed ) {
            txInterval = 30000;          // Change Tx interval to 30 secs
       } else {
        // Interval inbetween low and high speed 
            txInterval = (highSpeed / gps.speed.kmph()) * 30000;       
       } // endif
      
   }  // endof gps.time.isUpdated()
               
 ////////////////////////////////////////////////////////////////////////////////////
 // Check for when to Tx packet
 ////////////////////////////////////////////////////////////////////////////////////
 
  lastTx = millis() - txTimer;

  // Only check the below if locked satellites < 3

   if ( gps.satellites.value() > 3 ) {
    if ( lastTx > 5000 ) {
        // Check for heading more than 25 degrees
        if ( (headingDelta < -25 || headingDelta >  25) && lastTxdistance > 5 ) {
            if (TxtoRadio(1)) {
                lastTxdistance = 0;   // Ensure this value is zero before the next Tx
                previousHeading = currentHeading;
            }
        } // endif headingDelta
    } // endif lastTx > 5000
    
    if ( lastTx > 10000 ) {
         // check of the last Tx distance is more than 600m
         if ( lastTxdistance > 600 ) {  
            if ( TxtoRadio(2) ) {
                lastTxdistance = 0;   // Ensure this value is zero before the next Tx
            }
       } // endif lastTxdistance
    } // endif lastTx > 10000
    
    if ( lastTx >= txInterval ) {
        // Trigger Tx Tracker when Tx interval is reach 
        // Will not Tx if stationary bcos speed < 5 and lastTxDistance < 20
        if ( lastTxdistance > 20 ) {
              TxtoRadio(3); 
        } // endif lastTxdistance > 20 
    } // endif of check for lastTx > txInterval
    
    // Force a tx when 3 unique stations was received 
    // Or 60 secs after last received station to prevent stale info on the distance 
    if (  (rxStation > 2) || (( (rxStation > 0) && ( ((millis()-lastRx)/1000) > 60) )) )  {
           TxtoRadio(4);
     }
   } // Endif check for satellites
     
    // Check if the analog0 is plugged into 5V and more than 10 secs

    // rev13 PCB will change to pullup circuit and read using digitalRead() instead of analogRead
    
    if ( analogRead(0) > 700 && (lastTx > 10000) ) {
          buttonPressed = 1;                                  
          TxtoRadio(5); 
     } // endif check analog0

     
} // end loop()

// New MicroAPRS function
void show_packet()
{
	char *posit, *pmsgTo, *call, *pcomment, *pmsg;
	char type, pmsgID;
	long lat, lon;

        // Only displasy if decode is true
	if ( microaprs.decode_posit(packet, &call, &type, &posit, &lon, &lat, &pcomment, &pmsgTo, &pmsg, &pmsgID) ) {

	if (type == 58) // 58 = "!" = Message
	{
		if (startsWith(MYCALL, pmsgTo))
		{
                    mCounter++;
#ifdef OLED
                    oled.setCursor(2,0);
                    clear3Line();                        
                    oled.setCursor(2,0);
                    //oled.print("F:");
                    oled.setTextSize(2,1);
                    oled.print(call);
                    oled.setTextSize(1,1);                    
                    oled.setCursor(4,0);
                    oled.print("M:");
                    oled.print(pmsg);
#endif                    
                    // Beep 3 times
                    beep(3);
                    		}
	}
	else // Not message, decode , calculate and display packets
	{   		
            wayPointLatitude = lat;		
            wayPointLongitude = lon;

            wayPointLatitude = wayPointLatitude / 1000000;
	    wayPointLongitude = wayPointLongitude / 1000000;

	    distanceToWaypoint = calculateDistance();
	    bearing = calculateBearing();
  
            // Beep twice is station is less than 500m
            if ( distanceToWaypoint < 0.5 ) {
                 beep(2);
            }
            
            // Check for valid decoded packets
            if ( strlen(call) < 12 ) {
            lastRx = millis();
            packetDecoded++;
            
            // Append rx callsign into rxCallsign strings
            // Do not add own callsign
            if ( !startsWith(MYCALL,call) ) {
                // Do not add duplicated callsign from digipeater packets
        	if ( !rxCallsign.startsWith(call) ) {
			rxCallsign.concat(" ");
			rxCallsign.concat(call);
                        lastCall = call;
                        // Only send distance if GPS is locked AND less than 500km away
                        if ( gps.satellites.value() > 3 && distanceToWaypoint < 500 ) {
			    rxCallsign.concat("/");
			    rxCallsign.concat(distanceToWaypoint);
			    rxCallsign.concat("km");
                        } 
			rxStation++;
                 }
	    }

#ifdef OLED

                    oled.setCursor(2,0);
                    clear6Line();
                    oled.setCursor(2,0);
                    oled.setTextSize(2,1);
                    oled.print(call);
                    oled.setTextSize(1,1);  

                    if (distanceToWaypoint < 1000 ) {
                        oled.setCursor(4,0);                    
                        oled.print("B:");
                        oled.print(bearing, 0);
                        oled.print("deg D:");                      
                        oled.print(distanceToWaypoint,1); 
                        oled.print("km");
                        oled.setCursor(5,0);
                        oled.print(pcomment);
                    } else {
                        oled.setCursor(4,0);
                        oled.print(pcomment);
                    }

#endif

#ifdef I2C16X2
          packetDisplay = 1;
          displayTime = millis();
          lcdScreen4(call,pcomment);
#endif
                
	      } // endif check for valid packets
	}
    } // endif microaprs.decode_posit()
}



#ifdef I2C16X2
void lcdScreen1() {
  lcd.clear();
  displayLargeSpeed((unsigned int)gps.speed.kmph());
}

void lcdScreen2() {

  lcd.clear();  
  lcd.setCursor(0,0);
  lcd.print("B:");
  lcd.print(base,0);     // Max 999
  
  lcd.setCursor(6,0);
  lcd.print("T:");      
  lcd.print(txCounter);  // Max 999

   // Max 2 digits10w
 
  lcd.setCursor(12,0);
  lcd.print("R:");      
  lcd.print(packetDecoded);  // Max 99


  //lcd.setCursor(0,1);
  //lcd.print("M:");
  //lcd.print(mCounter);    // Messages received  
  
  //lcd.setCursor(0,1);
  //lcd.print("C:");
  //lcd.print((unsigned int)gps.course.deg());  

  lcd.setCursor(0,1);
  lcd.print("U:");
  lcd.print((float) millis()/60000,0); // Max 999

  lcd.setCursor(6,1);  
  lcd.print("A:");
  lcd.print((unsigned int)gps.altitude.meters()); // Max 9999
   
  //lcd.setCursor(12,1);
  //lcd.print("L:");
  //lcd.print((unsigned int)(millis()-lastRx)/1000);  // Print the seconds since last Rx

}

void lcdScreen3() {
     lcd.clear();  
     lcd.setCursor(0,0);
  
     // Convert to GMT+8
     byte hour = gps.time.hour() +8;
      
     if ( hour > 23 ) {
         hour = 0;
     }  
     if ( hour < 10 ) {
        lcd.print("0");       
     }  
       lcd.print(hour);         
       lcd.print(":");  
     if ( gps.time.minute() < 10 ) {
        lcd.print("0");       
     }
       lcd.print(gps.time.minute());
       lcd.print(":");
     if ( gps.time.second() < 10 ) {
       lcd.print("0");       
     }       
       lcd.print(gps.time.second());


  lcd.print(" H:");
  lcd.print(gps.hdop.value());
  
  lcd.setCursor(0,1);
  lcd.print(gps.location.lat(),4);
  lcd.setCursor(8,1);
  lcd.print(gps.location.lng(),4);
}

void lcdScreen4(char *callsign, char *comment ) {
 
       lcd.setCursor(0,0);
       lcd.clear();
       lcd.print(callsign);
            if (distanceToWaypoint < 500 ) {
                lcd.print(" ");
                lcd.print(distanceToWaypoint,1);
                lcd.print("km");
            }
       lcd.setCursor(0,1);
       comment[16] = 0;
       lcd.print(comment);
}

#endif
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

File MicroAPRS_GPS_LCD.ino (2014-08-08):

/*
 Copyright (C) 2014 Stanley Seow <stanleyseow@gmail.com>

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
 github URL :-
 https://github.com/stanleyseow/ArduinoTracker-MicroAPRS
 
 This sketch configure the MicroAPRS for the proper callsign and ssid and
 read/write data coming in from the MicroAPRS via debug port
 
 Pin 0/1 (rx,tx) connects to Arduino with MicroAPRS firmware
 Pin 8,9 ( rx,tx ) connects to GPS module
 Pin 2,3 connect to debug serial port
 
 Pin 10 - Buzzer during Radio Tx
 
 Date : 03 July 2014
 Written by Stanley Seow
 e-mail : stanleyseow@gmail.com
 Version : 0.2
 
 Pls flash the modem Arduino with http://unsigned.io/microaprs/ with USBtinyISP
 This firmware does NOT have an Arduino bootloader and run pure AVR codes. Once you
 have done this, follow the instructions on the above URL on how to set it up.
 We will call this Arduino/atmega328 as the "modem". 
 
 To use with Arduino Tracker (this sketch), connect the Modem Tx(pin1) to Arduino Rx(pin8) and 
 Modem Rx(pin0) to Arduino Rx(pin9).
 
 I had dropped bytes when using Softwaredebug for the MicroAPRS modem and therefore
 I'm using AltSoftdebug instead. The GPS module is still on Softwaredebug and 
 the hardware debug is still used for debug Monitor.
 
 ***** To use this sketch, pls change your CALLSIGN and SSID below under configModem().
 
 History :-
 03 July 2014 :-
 - Initial released
 
 06 July 2014 :-
 - added checks for speed and idle speed, modify the Txinternal
 - remove all debug Monitor output
 
 12 July 2014 :-
 - Added SmartBeaconing algorithm, Tx when turn is more than 25 deg
 - Reduce the Tx interval
 
 14 July 2014 :-
 - Fixed coordinates conversion from decimal to Deg Min formula
 - Formula to calculate distance from last Tx point so that it will Tx once the max direct distance 
  of 500m is reached
 
 18 July 2014 :-
 - Fixed lastTx checking routine and ensure lastTx is 5 or more secs
 - Check for analog0 button at least 10 secs per Tx
 - Rewrote the DecodeAPRS functions for display to LCD only
 
 1 Aug 2014 :-
 - Ported codes to Arduino Mini Pro 3.3V
 - Due to checksum errors and Mini Pro 3.3V 8Mhz on SoftwareSerial, I swapped GPS ports to AltSoftwareSerial
 
 3 Aug 2014 :-
 - Added #define codes to turn on/off LCD, DEBUG and TFT
 - Added TFT codes for 2.2" SPI TFT ( runs on 3.3V )
 - Added the F() macros to reduce memory usages on static texts
 
 6 Aug 2014
 - Added Course/Speed/Alt into comment field readable by aprs.fi
 - 
 
 TODO :-
 - implement compression / decompression codes for smaller Tx packets
 - Telemetry packets
 - Split comments and location for smaller Tx packets
 
 Bugs :-
 
 - Not splitting callsign and info properly
 - Packets received from Modem is split into two serial read
 - With TFT codes, the AltSoftSerial could not get the speed and course on time with lots of checksum errors
 - 
 
*/

// Needed this to prevent compile error for #defines
#if 1
__asm volatile ("nop");
#endif

// Turn on/off 20x4 LCD
#undef LCD20x4
// Turn on/off debug
#define DEBUG
// Turn on/off 2.2" TFT
#undef TFT22

#ifdef TFT22
#include <SPI.h>
#include <Adafruit_GFX.h>
#include <Adafruit_ILI9340.h>
#define _sclk 13
#define _miso 12
#define _mosi 11
#define _cs 7
#define _dc 6
#define _rst 5
Adafruit_ILI9340 tft = Adafruit_ILI9340(_cs, _dc, _rst);
#endif

#ifdef DEBUG 
#include <SoftwareSerial.h>
#endif

#include <AltSoftSerial.h>
#include <TinyGPS++.h>
#include <LiquidCrystal.h>



#ifdef LCD20x4
// My wiring for LCD on breadboard
LiquidCrystal lcd(12, 11, 4, 5, 6, 7);
#endif

#define VERSION "SVTrackR v0.4 " 

// Altdebug default on UNO is 8-Rx, 9-Tx
//AltSoftSerial ss;
AltSoftSerial ss(8,9);
TinyGPSPlus gps;

#ifdef DEBUG
// Connect to GPS module on pin 9, 10 ( Rx, Tx )
SoftwareSerial debug(2,3);
#endif

// Pin for Tx buzzer
const byte buzzerPin = 4;
unsigned int txCounter = 0;
unsigned long txTimer = 0;
unsigned long lastTx = 0;
unsigned long txInterval = 80000L;  // Initial 60 secs internal

int lastCourse = 0;
byte lastSpeed = 0;

int previousHeading, currentHeading = 0;
// Initial lat/lng pos, change to your base station coordnates
float lastTxLat = 3.16925, lastTxLng =  101.64972;
float lastTxdistance, homeDistance = 0.0;

const unsigned int MAX_DEBUG_INPUT = 30;

void setup()
{
#ifdef LCD20x4  
  // LCD format is Col,Row for 20x4 LCD
  lcd.begin(20,4);
  lcd.clear();
  lcd.setCursor(0,0);
  lcd.print("Arduino OpenTrackR"); 
#endif  

#ifdef TFT22
  tft.begin();    
  tft.setRotation(1);
  tft.setCursor(0,0);
  tft.setTextSize(3); 
  tft.setTextColor(ILI9340_WHITE);  
  tft.print("OpenTrackR"); 
  delay(1000);
  tft.fillScreen(ILI9340_BLACK);

#endif

// This is for buzzer
//pinMode(4, OUTPUT);
  
  Serial.begin(9600);
#ifdef DEBUG
  debug.begin(9600);
#endif
  ss.begin(9600);

#ifdef DEBUG
  debug.flush();
  debug.println();
  debug.println();
  debug.println(F("=========================================="));
  debug.print(F("DEBUG:- ")); 
  debug.println(F(VERSION)); 
  debug.println(F("=========================================="));
  debug.println();
#endif

  // Set a delay for the MicroAPRS to boot up before configuring it
  delay(1000);
  configModem();
  
  txTimer = millis();
 
} // end setup()


///////////////////////////////////////////////////////////////////////////////////////////////////////
void loop()
{
    // Speed in km/h
    const byte highSpeed = 80;       // High speed  
    const byte lowSpeed = 30;        // Low speed
    char c;
    boolean inputComplete = false;
    int headingDelta = 0;
    const double HOME_LAT = 3.16925 , HOME_LON = 101.64972;
    
#ifdef DEBUG    
    // Send commands from debug serial into hw Serial char by char 
    debug.listen();
    if ( debug.available() > 0  ) {
          processIncomingDebug(debug.read());
    }
#endif    
    
    // Turn on listen() on GPS
    ss.listen();                    
    while ( ss.available() > 0 ) {
      gps.encode(ss.read());
    }
    
///////////////// Triggered by location updates /////////////////////// 
   if ( gps.location.isUpdated() ) { 

     homeDistance = TinyGPSPlus::distanceBetween(
          gps.location.lat(),
          gps.location.lng(),
          HOME_LAT, 
          HOME_LON);   
          
    lastTxdistance = TinyGPSPlus::distanceBetween(
          gps.location.lat(),
          gps.location.lng(),
          lastTxLat,
          lastTxLng);
     
    } // endof gps.location.isUpdated()

///////////////// Triggered by time updates /////////////////////// 
// Update LCD every second

   if ( gps.time.isUpdated() ) {   
    
   // Turn on LED 13 when Satellites more than 3  
   // Disable when using TFT / SPI
   if ( gps.satellites.value() > 3 ) {
     digitalWrite(13,HIGH);  
   } else {
     digitalWrite(13,LOW);     
   }
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

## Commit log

2014-07-04 Initial commit
    This is the initial commit …
2014-07-07 Updates and bug fixes
    Added check for gps lock, current speed and tx interval
    [MicroAPRS_GPS_LCD.ino]
2014-07-15 Updates and bug fixes 0.3a
    Fixes to course change formula
    Fixes to speed detection / Tx interval formula
    Added timestamp to debugging messages
    [MicroAPRS_GPS_LCD.ino]
2014-07-17 Updates and bug fixes to txInternal timeout
    [MicroAPRS_GPS_LCD.ino]
2014-08-03 Added #ifdef for LCD20x4, DEBUG and TFT22
    Added #defines, ported to Arduino Mini Pro 3.3V
2014-08-08 Fixed -ve txInternal bug...
    [MicroAPRS_GPS_LCD.ino]
2014-08-18 Updates README.md on Arduino library needed
2014-08-26 Updates and bug fixes
    Added sequence number to the Tx counter to check for dropped packets
    [SVTrackR.ino]
2014-09-19 Modify button codes
    Modify button action to send Status. If gps is locked, the position
    will also be sent.
2014-10-14 Update to version 0.8
    - Added support for BeiDou GPS
    - Tx without GPS lock when button is pressed
2014-11-20 Updated to Ver 0.9 with 0.96" OLED support
    Added 0.96” SPI OLED support
    Packet Decoding codes
    Remove all 2.2” TFT codes
2015-03-16 Added custom comments to APRS packets and fixed the hardcoding of North and East on GPS positions
    [SVTrackR.ino]
2015-03-16 Fixes hardcoded padded 0 if front of Lat/Lng
    Fixes padded 0 when lat/lng less than 10
    Fixes oled display E/W and N/S
    Fixes oled display 0 padding
    [SVTrackR.ino]
2015-03-26 Fixed append of zero to negative coordinates. Created beep function to save memory.
    [SVTrackR.ino]
2015-04-07 Fixes hard coded 0 in Lng ... added a checking if Lng is less than 100 deg
    [SVTrackR.ino]
2015-04-25 Added received stations and distance in comment field
    - add TxtoRadio with return values and tx trigger reasons ( H -
    heading, T - time, D - Distance, B - button, R - Rx station )
    - removed unused variables
    - fixes some tx timer codes
    [SVTrackR.ino]
2015-04-25 Updates SSD1306_text libs to support Arduino 1.6.x
2015-05-03 Added Eagle CAD PCB drawings to the repo
    [Arduino_V7 OLED.brd, Arduino_V7 OLED.sch, Modem_V3.brd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]
2015-10-02 Upgrade to 1.62 with support for I2C 16x2LCD
    - Adding support for I2C 16x2 for Dashboard LCD
    - Added 3 screens for speed/sats/headings, date/pos and other stats
    - Added N/E/S/W into main screen
2016-10-31 Updates EagleCAD files
    [Arduino_V13_5x5.brd, Arduino_V13_5x5.sch, Modem_V20_5x5.brd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]

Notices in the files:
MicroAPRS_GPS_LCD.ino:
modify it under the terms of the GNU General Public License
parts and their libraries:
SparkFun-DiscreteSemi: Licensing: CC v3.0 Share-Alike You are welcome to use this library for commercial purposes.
